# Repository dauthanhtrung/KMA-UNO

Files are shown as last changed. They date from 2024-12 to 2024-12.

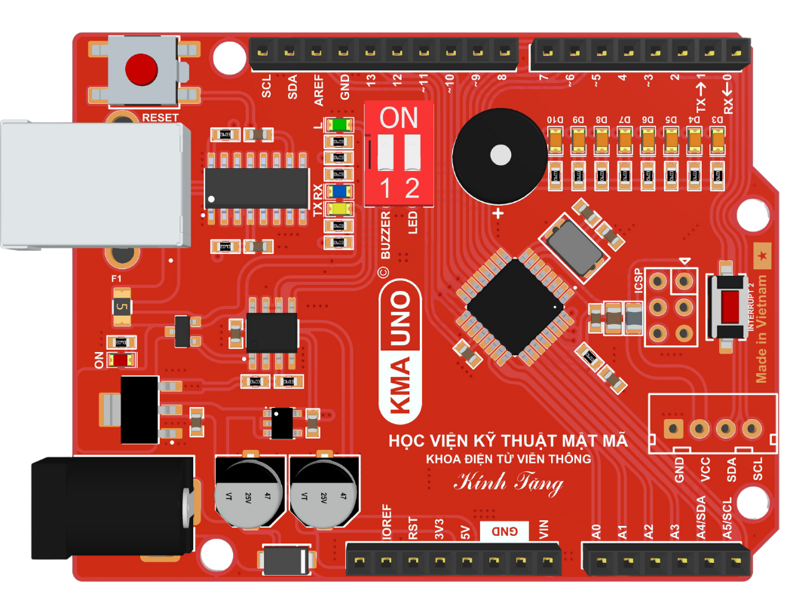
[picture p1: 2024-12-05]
Image/ARDUINO_UNO-KMA_3D TOP.PDF.png

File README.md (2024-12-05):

# Arduino Uno Limited Version KMA

Cách tự làm một bảng Arduino phiên bản giới hạn dành riêng cho sinh viên Học viện Kỹ thuật Mật mã!

## Authors

- Facebook: [Đậu Thành Trung](https://www.facebook.com/dauthanhtrung.kma/)

- Email: dauthanhtrung.kma@gmail.com
## Demo
https://dauthanhtrung.wordpress.com/2024/11/18/how-to-make-arduino-uno-limited-version-kma/
## 🔗 Contact


## Screenshots

App Screenshot
App Screenshot
App Screenshot

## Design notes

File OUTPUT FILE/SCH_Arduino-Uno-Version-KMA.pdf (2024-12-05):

# Arduino UNO Limited Version KMA

# C1 100nF/0603 GND

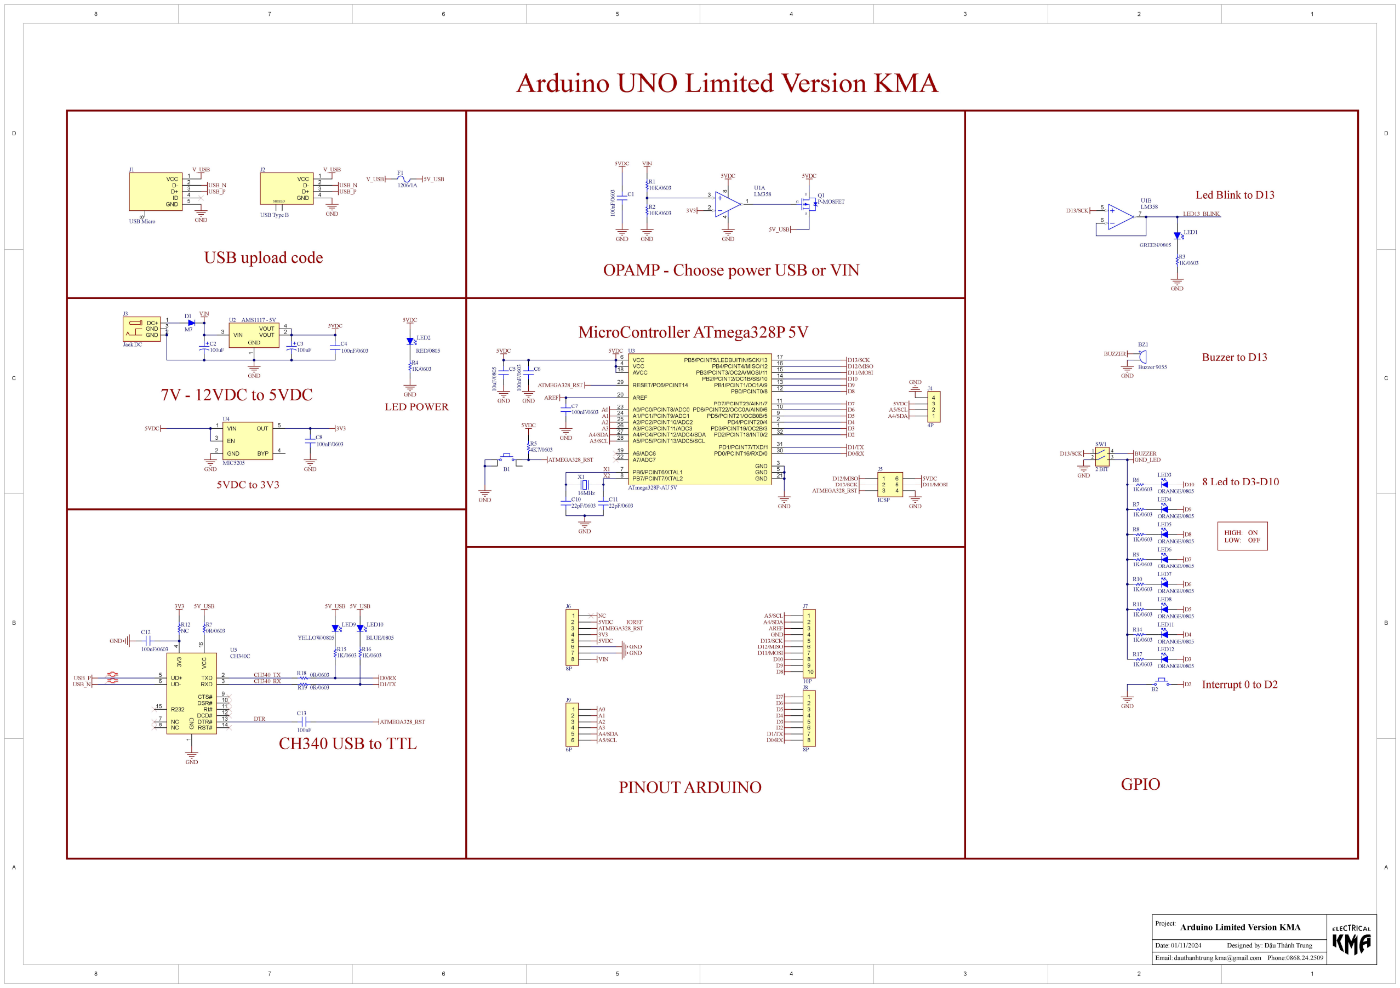
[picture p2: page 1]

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
Project:

Date: | Designed by: 01/11/2024

## Arduino Limited Version KMA

Đậu Thành Trung
Email:dauthanhtrung.kma@gmail.com Phone:0868.24.2509

GND

V_USB

D12/MISO
D13/SCK | D11/MOSI
ATMEGA328_RST

R5
4K7/0603
ATMEGA328_RST
BUZZER | + BZ1
| Buzzer 9055
AREF 20 | PB0/PCINT0/8 | 12 PB1/PCINT1/OC1A/9 | 13 PB2/PCINT2/OC1B/SS/10 | 14 PB3/PCINT3/OC2A/MOSI/11 | 15 PB4/PCINT4/MISO/12 | 16 PB5/PCINT5/LEDBUITIN/SCK/13 | 17

PB6/PCINT6/XTAL1 7
PB7/PCINT7/XTAL2 8

A0/PC0/PCINT8/ADC0 23
A1/PC1/PCINT9/ADC1 24
A2/PC2/PCINT10/ADC2 25
A3/PC3/PCINT11/ADC3 26
A4/PC4/PCINT12/ADC4/SDA 27 A5/PC5/PCINT13/ADC5/SCL 28

RESET/PC6/PCINT14 29

AVCC 18 VCC 4

VCC 6

PD0/PCINT16/RXD/0 | 30 PD1/PCINT7/TXD/1 | 31
PD2/PCINT18/INT0/2 | 32 PD3/PCINT19/OC2B/3 | 1
PD4/PCINT20/4 | | 2
PD5/PCINT21/OCB0B/5 | 9
PD6/PCINT22/OCC0A/AIN0/6 | 10 PD7/PCINT23/AIN1/7 | 11

A6/ADC6 19
A7/ADC7 22
GND | 3
GND | 5
GND | 21

U3

ATmega328P-AU 5V

C10
22pF/0603

C11
22pF/0603

GND

GND

ATMEGA328_RST

5VDC

C7
100nF/0603

GND

X1

16MHz

USB_N

USB_P

LED10

BLUE/0805

LED9

YELLOW/0805

R16
1K/0603

R15
1K/0603 GND

1

TXD | 2
RXD | 3 ³V³

4

UD+ 5
UD- 6

NC 7
NC 8
CTS# | 9
DSR# | 10
RI# | 11
DCD# | 12
DTR# | 13
RST# | 14
R232 15 | VCC ¹⁶
U5
CH340C

C13

100nF

C12

100nF/0603

3V3

R18 0R/0603

R19 0R/0603

CH340_TX
CH340_RX

5V_USB 5V_USB

ATMEGA328_RST

USB_N
USB_P
C6 100nF/0603 C5 10uF/0805 GND | GND

5VDC

# USB upload code

# MicroController ATmega328P 5V

# CH340 USB to TTL

R12
NC

5V_USB

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
DC+ 1
GND 3
GND 2

J3

Jack DC

1

3

2 4 8

U1A
LM358
VIN 3 | VOUT | 2
GND1
| VOUT | 4

U2 AMS1117 - 5V

C2
100uF

C3
100uF

7

5

6

U1B
LM358

D1

M7

3V3

NC
5VDC

VIN

GND
GND

A0
A1
A2
A3
A4/SDA
A5/SCL

D5
D4
D3
D2
D1/TX
D0/RX

D10
D9
D8

D6

D7

AREF
GND

A4/SDA

A5/SCL

A0
A1
A2
A3
A4/SDA
A5/SCL

D5
D4
D3
D2

D11/MOSI
D10
D9
D8

D6

D7

D13/SCK
D12/MISO

D1/TX
D0/RX

VIN

5VDC

ATMEGA328_RST

V_USB

USB_N
USB_P

GND

GND

1
2 3

4

SW1

### 2 BIT

AREF

D1/TX

D0/RX

X1
X2 | LED3
| ORANGE/0805
| LED4
| ORANGE/0805
| LED5
| ORANGE/0805
| LED6
| ORANGE/0805
| LED7
| ORANGE/0805
| LED8
| ORANGE/0805
| LED11
| ORANGE/0805
| LED12
| ORANGE/0805

R6
1K/0603

R7
1K/0603

R8
1K/0603

R9
1K/0603

R10
1K/0603

R11
1K/0603

R14
1K/0603

R17
1K/0603

BUZZER
GND_LED

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
D11/MOSI

D13/SCK
D12/MISO

D13/SCK

C4
100nF/0603

# 7V - 12VDC to 5VDC

5VDC

GND

D13/SCK

LED1

GREEN/0805

R3
1K/0603

LED2

RED/0805

R4
1K/0603

5VDC

GND

LED13_BLINK

R1
10K/0603

R2
10K/0603

VIN

GND

3V3

G

D

S

Q1
P-MOSFET

5VDC

5V_USB

OUT | 5
BYP | 4

EN 3

VIN 1

GND 2

U4

MIC5205

3V3
C8
100nF/0603
GND | GND

5VDC

# 5VDC to 3V3

# OPAMP - Choose power USB or VIN

V_USB | 5V_USB

GND

# LED POWER

5VDC

B1

IOREF

5VDC

1
2
3 4

5

6

J5

ICSP

5VDC

GND

5VDC

GND

A4/SDA

A5/SCL

F1

1206/1A

GND

B2

GND

GND

VCC | 1
D- | 2
D+ | 3
GND | 4

SHIELD

J2

USB Type B

VCC | 1
D- | 2
D+ | 3
ID | 4
GND | 5 S

J1

USB Micro

PINOUT ARDUINO | GPIO

1

2

3

4

J4

4P

R?
0R/0603

5VDC

DTR

HIGH: ON
LOW: OFF

# Interrupt 0 to D2

# 8 Led to D3-D10

# Buzzer to D13

# Led Blink to D13

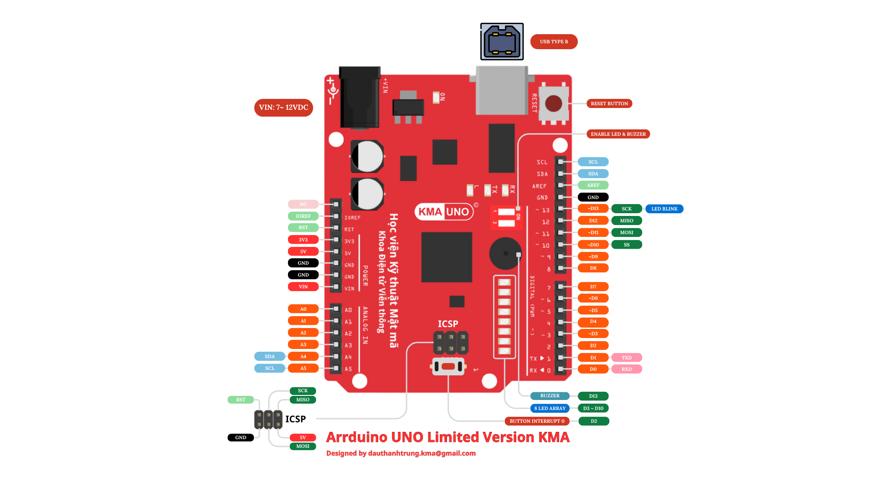
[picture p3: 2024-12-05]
Image/KMA-Uno-Pinout.png

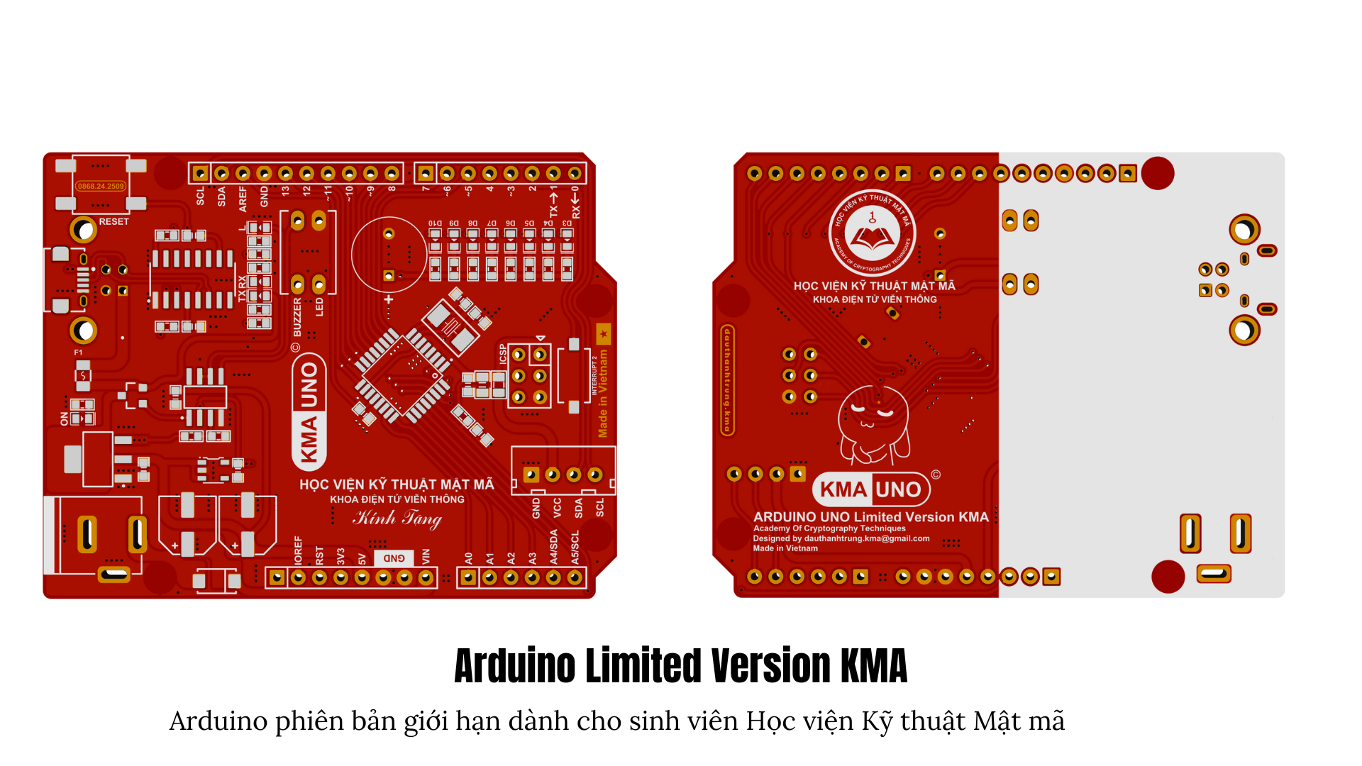
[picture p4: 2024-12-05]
Image/KMA-Uno-Board.png

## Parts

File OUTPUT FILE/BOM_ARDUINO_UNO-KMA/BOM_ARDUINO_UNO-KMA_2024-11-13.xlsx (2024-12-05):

DANH SÁCH LINH KIỆN - BOMLIST
Bill of Materials for Project [ARDUINO_UNO-KMA.PrjPcb] (No PCB Document Selected)
KMA ELECTRICAL |  |  | Project Name: | ARDUINO_UNO-KMA.PrjPcb | Report Date: | 13/11/2024
 |  |  | Author: | Thành Trung |  | 03:30 PM
STT | Description | Comment | Footprint | Designator | Quantity | Note
1 | Nút nhấn 4 chân | =Value | BUTTON-SMD-4P-6X6X3.1MM | B1 | 1
2 | Nút nhấn 2 chân | =Value | BUTTON-SMD-2P-3x6x5MM | B2 | 1
3 | Còi chip | Buzzer 9055 | BUZZER_9055 | BZ1 | 1
4 | Tụ dán | 100nF/0603 | CAP-0603 | C1, C4, C6, C7, C8, C9, C12 | 7
5 | Tụ hoá dán | 100uF | CAPP-SMD-ALU-6.3X5.4MM-D | C2, C3 | 2
6 | Tụ dán | 10uF/0805 | CAP-0805 | C5 | 1
7 | Tụ dán | 22pF/0603 | CAP-0603 | C10, C11 | 2
8 | Tụ dán | 100nF | CAP-0603 | C13 | 1
9 | Diode SMD | M7 | DIODE-SMD-DO-214AC | D1 | 1
10 | Ferrite Beads | 0R | FB-0805 | E1 | 1
11 | Cầu chì SMD | 1A | FUSE-SMD-PTC-1206 | F1 | 1
12 | Cổng USB 5P | USB | USB-FEMALE-MICRO-DIP | J1 | 1
13 | Cổng USB TYPE B | USB Type B | USB-FEMALE-TYPE-B | J2 | 1
14 | Jack nguồn DC | Jack DC | JACK-DC-5.5X2.1MM | J3 | 1
15 | Jump 8P | 8P | JUMP-2.54-FEMALE-8P | J6, J8 | 2
16 | Jump 10P | 10P | JUMP-2.54-FEMALE-10P | J7 | 1
17 | Jump 6P | 6P | JUMP-2.54-FEMALE-6P | J9 | 1
18 | Led dán | GREEN/0805 | LED-0805-GREEN | LED1 | 1
19 | Led dán | RED/0805 | LED-0805-RED | LED2 | 1
20 | Led dán | ORANGE/0805 | LED-0805-ORANGE | LED3, LED4, LED5, LED6, LED7, LED8, LED11, LED12 | 8
21 | Led dán | YELLOW/0805 | LED-0805-YELLOW | LED9 | 1
22 | Led dán | BLUE/0805 | LED-0805-BLUE | LED10 | 1
23 | Mosfet kênh P PNP dán | P-MOSFET | MOSFET-SOT23-123 | Q1 | 1
24 | Điện trở dán | 10K/0603 | RES-0603 | R1, R2 | 2
25 | Điện trở dán | 1K/0603 | RES-0603 | R3, R4, R6, R7, R8, R9, R10, R11, R14, R15, R16, R17 | 12
26 | Điện trở dán | 4K7/0603 | RES-0603 | R5 | 1
27 | Điện trở dán | NC | RES-0603 | R12 | 1
28 | Điện trở dán | 0R/0603 | RES-0603 | R13, R18, R19 | 3
29 | Công tắc 2 bit | 2 BIT | BIT-SW-2P | SW1 | 1
30 | IC LM358 OPAMP | LM358 | SOP-8 | U1 | 1
31 | IC AMS1117 IC Nguồn 5V 1A SOT-223 | AMS1117 - 5V | SOT-223 | U2 | 1
32 | IC ATmega328P IC MCU 8BIT 32KB FLASH 32P | ATmega328P | TQFP-32 | U3 | 1
33 | IC nguồn MIC5205-3.3 KB33 0.15A 3.3V SOT23-5 | MIC5205 | SOT-23-5 | U4 | 1
34 | IC CH340C Chuyển đổi USB to TTL 2Mbps USB2.0 SOP-16 | CH340C | SOP-16 | U5 | 1
35 | Thạch anh 2P | 16MHz | CRYSTAL-SMD-5032-2P | X1 | 1
36 | Thạch anh 2P | 16MHz | CRYSTAL-DIP | X2 | 1

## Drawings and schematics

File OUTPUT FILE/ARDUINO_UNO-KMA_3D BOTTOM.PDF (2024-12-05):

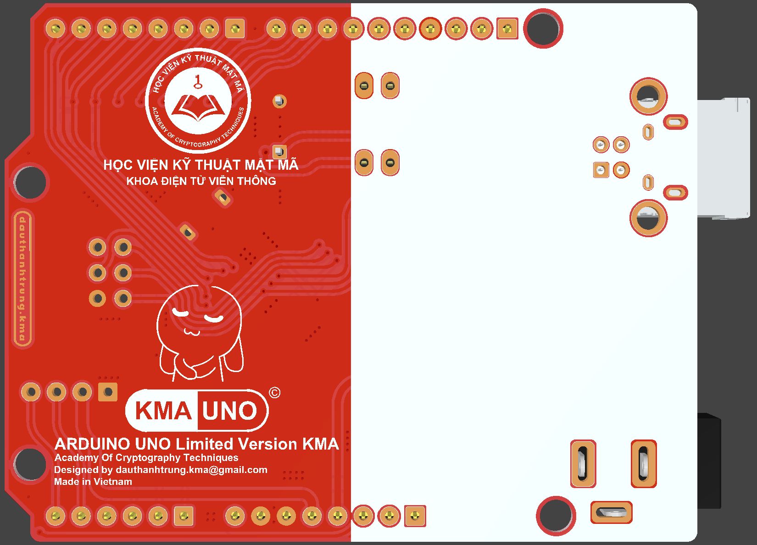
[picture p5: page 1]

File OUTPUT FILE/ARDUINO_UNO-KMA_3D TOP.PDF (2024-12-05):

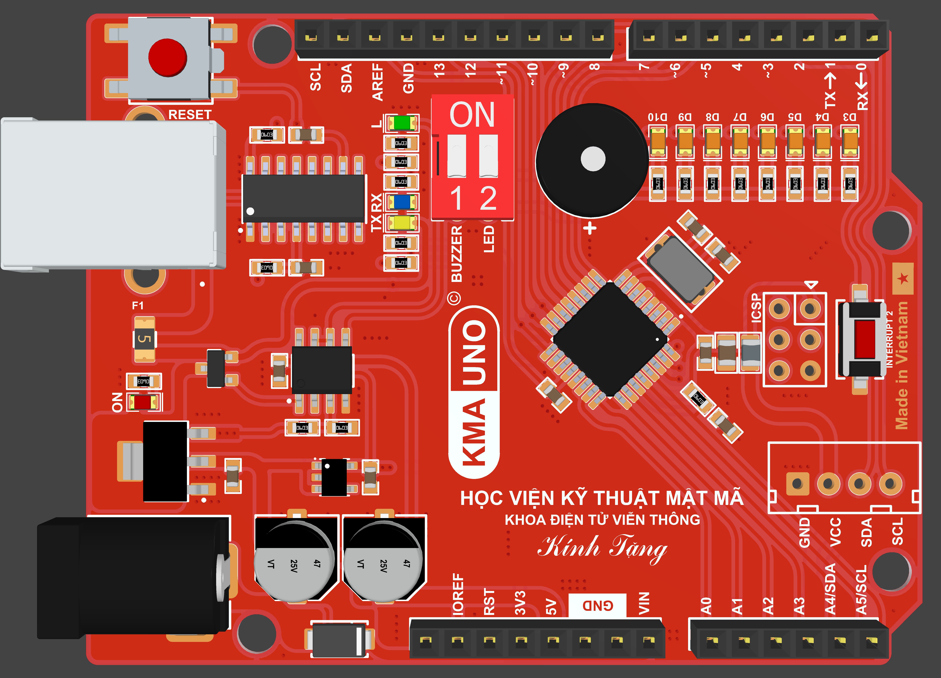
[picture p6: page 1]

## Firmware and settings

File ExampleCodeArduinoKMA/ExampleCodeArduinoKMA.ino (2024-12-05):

/*
     _             _   _                 _     _
  __| | __ _ _   _| |_| |__   __ _ _ __ | |__ | |_ _ __ _   _ _ __   __ _
 / _` |/ _` | | | | __| '_ \ / _` | '_ \| '_ \| __| '__| | | | '_ \ / _` |
| (_| | (_| | |_| | |_| | | | (_| | | | | | | | |_| |  | |_| | | | | (_| |
 \__,_|\__,_|\__,_|\__|_| |_|\__,_|_| |_|_| |_|\__|_|   \__,_|_| |_|\__, |
                                                                    |___/
*/
//*****************************************************************//
// Copyright by Dau Thanh Trung
// Project: Example Code for Arduino UNO Limited Version KMA
// Date:    1/11/2024
// Author:  Dau Thanh Trung
// Phone:   0868.24.25.09
// Mail:    dauthanhtrung.kma@gmail.com
// Site:    www.facebook.com/dauthanhtrung.kma
// Git:     www.github.com/dauthanhtrung
//*****************************************************************//
//Khai báo các chân kết nối
//Cần phải gạt 2 công tắc bit ở trên KMA-UNO để led và còi hoạt động
#define BUTTON 2                           // Kết nối nút nhấn với pin 2 (hỗ trợ ngắt interrupt 2)
#define BUZZER 13                          // Kết nối với còi chip với pin 13
byte LED[] = { 3, 4, 5, 6, 7, 8, 9, 10 };  // Kết nối với LED từ pin 3 - pin 10

#define ON 1                   // ~HIGH Bật
#define OFF 0                  // ~LOW  Tắt
int time_delay = 100;          // Biến lưu thời gian delay của hiệu ứng
unsigned int MODE;             // Biến mode để lưu chương trình đang chạy theo chế độ
void CheckButtonInterrupt() {  //Chương trình ngắt
  MODE++;                      //Chuyển đổi giữa các chế độ dùng ngắt
  if (MODE > 10) MODE = 0;     //có 10 chương trình nháy led
}
void bip(uint16_t time_delay) {  //còi chip kêu theo thời gian được set
  digitalWrite(BUZZER, ON);
  delay(time_delay);
  digitalWrite(BUZZER, OFF);
  delay(time_delay);
}
void setup() {
  //Khởi tạo GPIO input, output
  for (int i = 0; i < 8; i++) {
    pinMode(LED[i], OUTPUT);    //Khởi tạo LED là OUTPUT
    digitalWrite(LED[i], OFF);  // Tắt các đèn
  }

  pinMode(BUZZER, OUTPUT);                            //Khởi tạo còi chip là OUTPUT
  pinMode(BUTTON, INPUT_PULLUP);                      //Khởi tạo nút nhấn với trở treo lên VCC
  attachInterrupt(0, CheckButtonInterrupt, FALLING);  //Khởi tạo ngắt ở pin 2
  MODE = 10;                                          //gọi chế độ mặc định là 10
  bip(100);                                           //còi chip kêu
  bip(100);
  // bip(200);
  // Khởi tạo thành công!
}

void loop() {  //Chương trình chính
  //Chọn chế độ để hoạt động theo chương trình con
  // if (!MODE) bip(200);
  switch (MODE) {
    case 0:
      MODE0();
      break;
    case 1:
      MODE1();
      break;
    case 2:
      MODE2();
      break;
    case 3:
      MODE3();
      break;
    case 4:
      MODE4();
      break;
    case 5:
      MODE5();
      break;
    case 6:
      MODE6();
      break;
    case 7:
      MODE7();
      break;
    case 8:
      MODE8();
      break;
    case 9:
      MODE9();
      break;
    case 10:
      MODE10();
      break;
  }
}
//************************Chương trình con******************************//
void All_OFF() {
  for (int i = 0; i < 8; i++) {
    digitalWrite(LED[i], OFF);  // tắt cả 8 led
  }
}
void All_ON() {
  for (int i = 0; i < 8; i++) {
    digitalWrite(LED[i], ON);  // bật cả 8 led
  }
}
void MODE0() {  //Chế độ 0: nhấp nháy led
  //int time_delay = 100;
  All_ON();
  delay(time_delay);
  All_OFF();
  delay(time_delay);
}
void MODE1() {  //Chế độ 1: sáng dồn từ dưới lên
  //int time_delay = 100;
  All_OFF();
  delay(time_delay);
  for (int i = 0; i < 8; i++) {
    digitalWrite(LED[i], ON);  // sáng dần
    delay(time_delay);
  }
}
void MODE2() {  //Chế độ 2: sáng dồn từ trên xuống
  //int time_delay = 100;
  All_OFF();
  delay(time_delay);
  for (int i = 7; i >= 0; i--) {
    digitalWrite(LED[i], ON);  // sáng dần
    delay(time_delay);
  }
}
void MODE3() {  //Chế độ 3: sáng dồn đảo
  //int time_delay = 100;
  All_OFF();
  delay(time_delay);
  for (int i = 0; i < 8; i++) {
    digitalWrite(LED[i], ON);
    delay(time_delay);
  }
  All_OFF();
  // delay(time_delay);
  for (int i = 7; i >= 0; i--) {
    digitalWrite(LED[i], ON);
    delay(time_delay);
  }
}
void MODE4() {  //Chế độ 4: led đơn đuổi từ dưới lên
  //int time_delay = 100;
  All_OFF();
  for (int i = 0; i < 8; i++) {
    digitalWrite(LED[i], ON);  // sáng dần
    digitalWrite(LED[i - 1], OFF);
    delay(time_delay);
  }
}
void MODE5() {  //Chế độ 5: led đơn đuổi từ trên xuống
  //int time_delay = 100;
  All_OFF();
  for (int i = 7; i >= 0; i--) {
    digitalWrite(LED[i], ON);  // sáng dần
    digitalWrite(LED[i + 1], OFF);
    delay(time_delay);
  }
}
void MODE6() {  //Chế độ 6: led đơn đuổi đảo qua lại
  //int time_delay = 100;
  All_OFF();
  for (int i = 0; i < 8; i++) {
    digitalWrite(LED[i], ON);  // sáng dần
    digitalWrite(LED[i - 1], OFF);
    delay(time_delay);
  }
  for (int i = 7; i >= 0; i--) {
    digitalWrite(LED[i], ON);  // sáng dần
    digitalWrite(LED[i + 1], OFF);
    delay(time_delay);
  }
}
void MODE7() {  //Chế độ 7: led sáng luân phiên chẵn lẻ
  //int time_delay = 100;
  digitalWrite(LED[0], ON);
  digitalWrite(LED[1], OFF);
  digitalWrite(LED[2], ON);
  digitalWrite(LED[3], OFF);
  digitalWrite(LED[4], ON);
  digitalWrite(LED[5], OFF);
  digitalWrite(LED[6], ON);
  digitalWrite(LED[7], OFF);
  delay(time_delay);
  digitalWrite(LED[0], OFF);
  digitalWrite(LED[1], ON);
  digitalWrite(LED[2], OFF);
  digitalWrite(LED[3], ON);
  digitalWrite(LED[4], OFF);
  digitalWrite(LED[5], ON);
  digitalWrite(LED[6], OFF);
  digitalWrite(LED[7], ON);
  delay(time_delay);
}
void MODE8() {  //Chế độ 8: led sáng luân phiên chẵn lẻ 2 led
  //int time_delay = 100;
  digitalWrite(LED[0], ON);
  digitalWrite(LED[1], ON);
  digitalWrite(LED[2], OFF);
  digitalWrite(LED[3], OFF);
  digitalWrite(LED[4], ON);
  digitalWrite(LED[5], ON);
  digitalWrite(LED[6], OFF);
  digitalWrite(LED[7], OFF);
  delay(time_delay);
  digitalWrite(LED[0], OFF);
  digitalWrite(LED[1], OFF);
  digitalWrite(LED[2], ON);
  digitalWrite(LED[3], ON);
  digitalWrite(LED[4], OFF);
  digitalWrite(LED[5], OFF);
  digitalWrite(LED[6], ON);
  digitalWrite(LED[7], ON);
  delay(time_delay);
}
void MODE9() {  //Chế độ 9: led sáng luân phiên 4 led
  //int time_delay = 100;
  digitalWrite(LED[0], ON);
  digitalWrite(LED[1], ON);
  digitalWrite(LED[2], ON);
  digitalWrite(LED[3], ON);
  digitalWrite(LED[4], OFF);
  digitalWrite(LED[5], OFF);
  digitalWrite(LED[6], OFF);
  digitalWrite(LED[7], OFF);
  delay(time_delay);
  digitalWrite(LED[0], OFF);
  digitalWrite(LED[1], OFF);
  digitalWrite(LED[2], OFF);
  digitalWrite(LED[3], OFF);
  digitalWrite(LED[4], ON);
  digitalWrite(LED[5], ON);
  digitalWrite(LED[6], ON);
  digitalWrite(LED[7], ON);
  delay(time_delay);
}
void MODE10() {  //Chế độ 10
  //int time_delay = 100;
  All_OFF();
  delay(time_delay);
  for (int i = 0; i < 8; i++) {
    digitalWrite(LED[i], ON);
    delay(time_delay);
  }
  // All_OFF();
  delay(time_delay);
  for (int i = 0; i < 8; i++) {
    digitalWrite(LED[i], OFF);
    delay(time_delay);
  }
  delay(time_delay);
  for (int i = 7; i >= 0; i--) {
    digitalWrite(LED[i], ON);
    delay(time_delay);
  }
  // All_OFF();
  delay(time_delay);
  for (int i = 7; i >= 0; i--) {
    digitalWrite(LED[i], OFF);
    delay(time_delay);
  }
}

//C:\Users\Admin\AppData\Local\Temp\arduino\sketches\BB10693D29FD9065922F1B8C0E2EADA0
